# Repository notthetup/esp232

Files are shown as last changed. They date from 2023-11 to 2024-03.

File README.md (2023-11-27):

# esp232
ESP32 + RS232 = 💰

This project is a simple PCB that allows you to connect an ESP32 to a RS232 port. The initial version is based on a Seeduino ESP32 Xiao board for simplicity.

## Features

- RS232 port with RTS/CTS flow control
- USB port for power and programming
- Seperate optional 5V power input
- Commonly available IDC connectors for connecting to RS232.

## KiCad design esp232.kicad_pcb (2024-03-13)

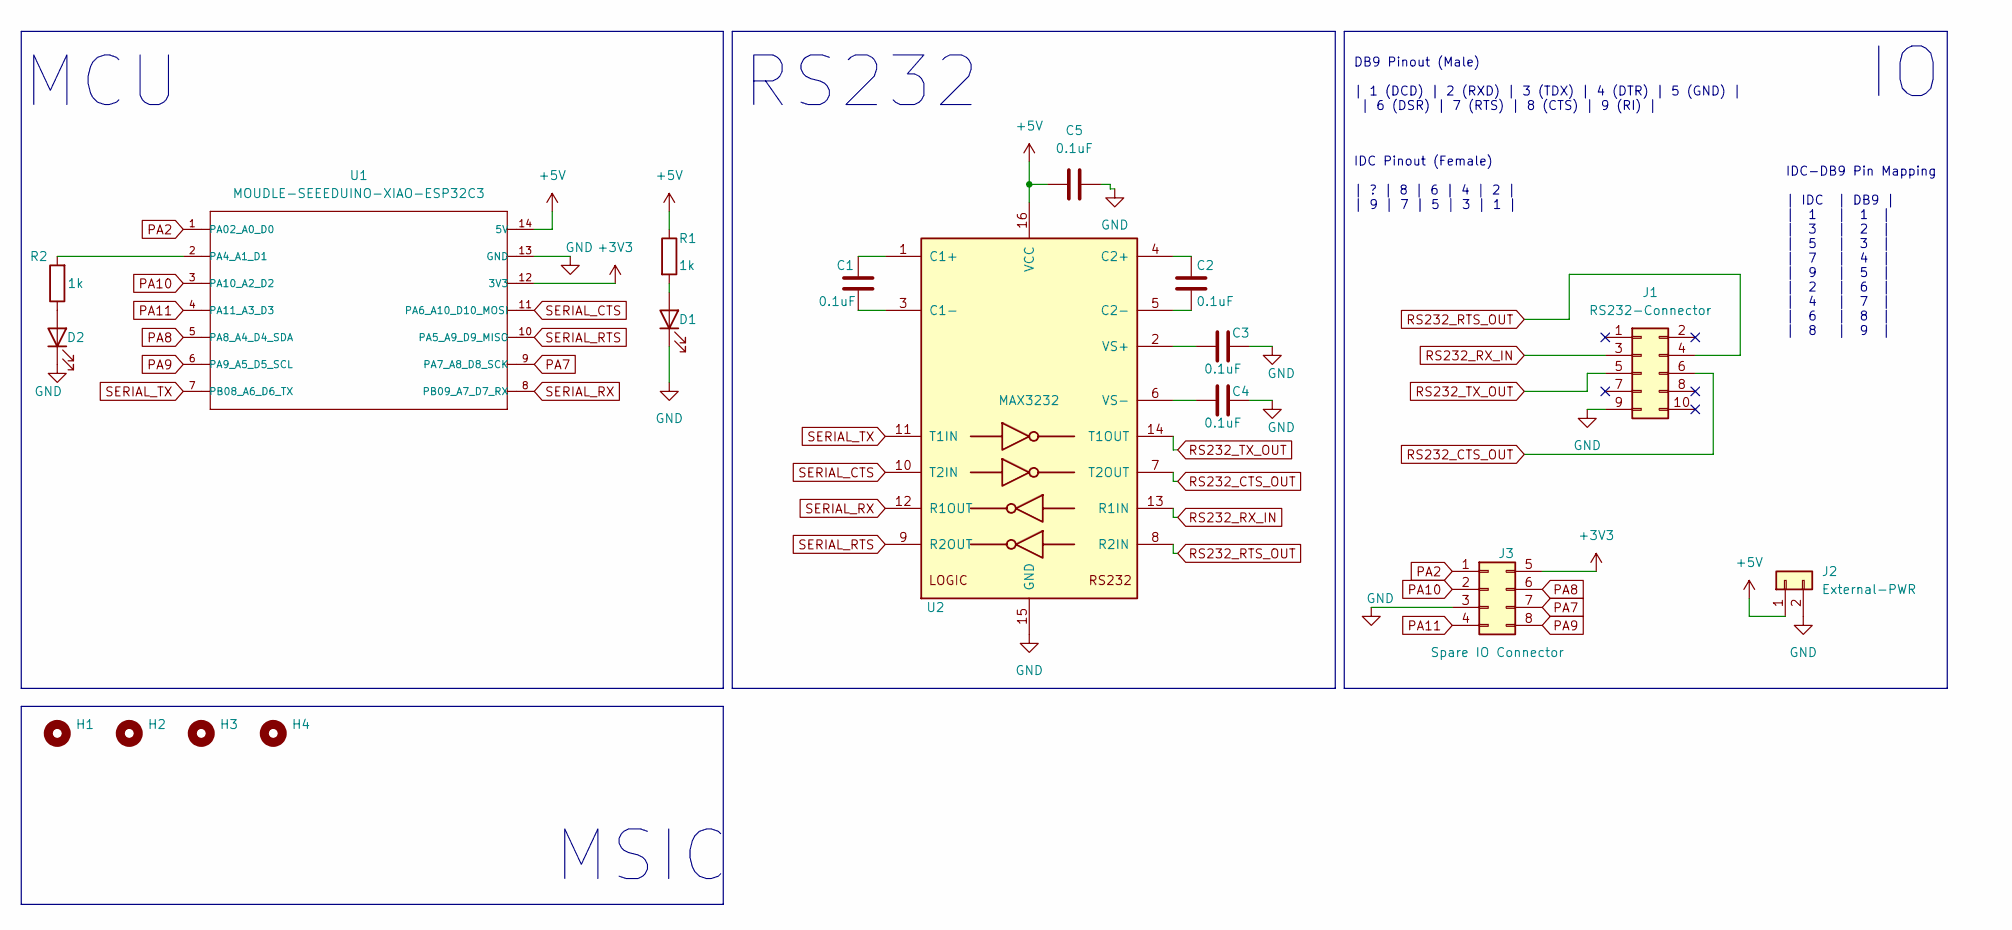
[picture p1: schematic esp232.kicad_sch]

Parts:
C1, C2, C3, C4, C5: 0.1uF; C_0805_2012Metric_Pad1.18x1.45mm_HandSolder
D1, D2: LED; LED_0805_2012Metric_Pad1.15x1.40mm_HandSolder
H1, H2, H3, H4: MountingHole; MountingHole_2.5mm
J1: RS232-Connector; IDC-Header_2x05_P2.54mm_Vertical
J2: External-PWR; PinHeader_1x02_P1.27mm_Vertical
J3: Spare IO Connector; PinHeader_2x04_P1.27mm_Vertical_SMD
R1, R2: 1k; R_0805_2012Metric_Pad1.20x1.40mm_HandSolder
U1: MOUDLE-SEEEDUINO-XIAO-ESP32C3; MOUDLE14P-SMD-2.54-21X17.8MM
U2: MAX3232; SOIC-16_3.9x9.9mm_P1.27mm

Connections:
+3V3: J3.5, U1.12 (3V3)
+5V: C5.1, J2.1, R1.1, U1.14 (5V), U2.16 (VCC)
GND: C3.2, C4.2, C5.2, D1.1 (K), D2.1 (K), J1.9, J2.2, J3.3, U1.13 (GND), U2.15 (GND)
unnamed: D1.2 (A), R1.2
unnamed: D2.2 (A), R2.1
unnamed: R2.2, U1.2 (PA4_A1_D1)
unnamed: C1.1, U2.1 (C1+)
unnamed: C1.2, U2.3 (C1-)
unnamed: C2.1, U2.4 (C2+)
unnamed: C2.2, U2.5 (C2-)
unnamed: C3.1, U2.2 (VS+)
unnamed: C4.1, U2.6 (VS-)
PA2: J3.1, U1.1 (PA02_A0_D0)
PA7: J3.7, U1.9 (PA7_A8_D8_SCK)
PA8: J3.6, U1.5 (PA8_A4_D4_SDA)
PA9: J3.8, U1.6 (PA9_A5_D5_SCL)
PA10: J3.2, U1.3 (PA10_A2_D2)
PA11: J3.4, U1.4 (PA11_A3_D3)
RS232_CTS_OUT: J1.6, U2.7 (T2OUT)
RS232_RTS_OUT: J1.4, U2.8 (R2IN)
RS232_RX_IN: J1.3, U2.13 (R1IN)
RS232_TX_OUT: J1.5, U2.14 (T1OUT)
SERIAL_CTS: U1.11 (PA6_A10_D10_MOSI), U2.10 (T2IN)
SERIAL_RTS: U1.10 (PA5_A9_D9_MISO), U2.9 (R2OUT)
SERIAL_RX: U1.8 (PB09_A7_D7_RX), U2.12 (R1OUT)
SERIAL_TX: U1.7 (PB08_A6_D6_TX), U2.11 (T1IN)

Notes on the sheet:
DB9 Pinout (Male) | 1 (DCD) | 2 (RXD) | 3 (TDX) | 4 (DTR) | 5 (GND) | | 6 (DSR) | 7 (RTS) | 8 (CTS) | 9 (RI) |
MCU
IDC Pinout (Female) | ? | 8 | 6 | 4 | 2 | | 9 | 7 | 5 | 3 | 1 |
IDC-DB9 Pin Mapping | IDC | DB9 | | 1 | 1 | | 3 | 2 | | 5 | 3 | | 7 | 4 | | 9 | 5 | | 2 | 6 | | 4 | 7 | | 6 | 8 | | 8 | 9 |
RS232
MSIC

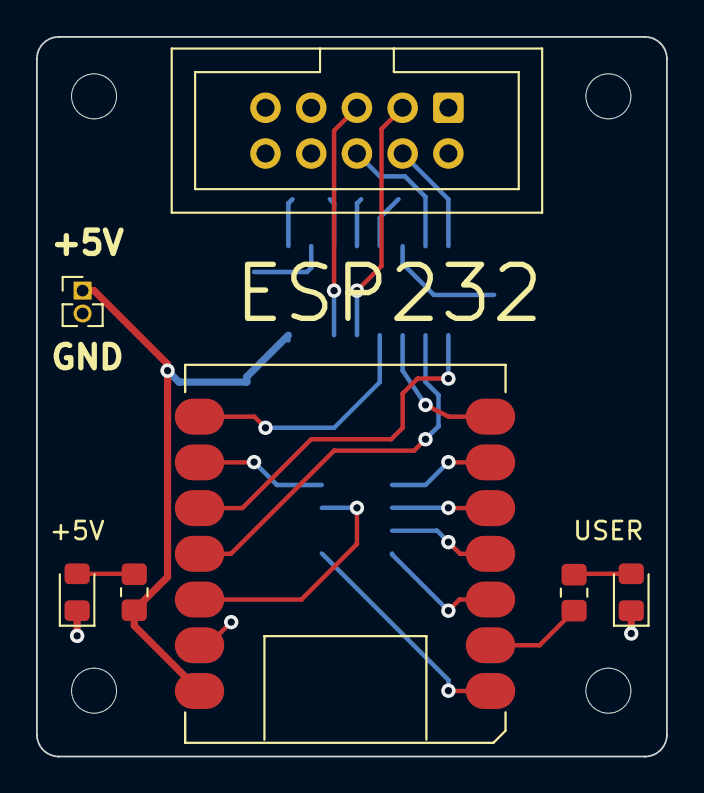
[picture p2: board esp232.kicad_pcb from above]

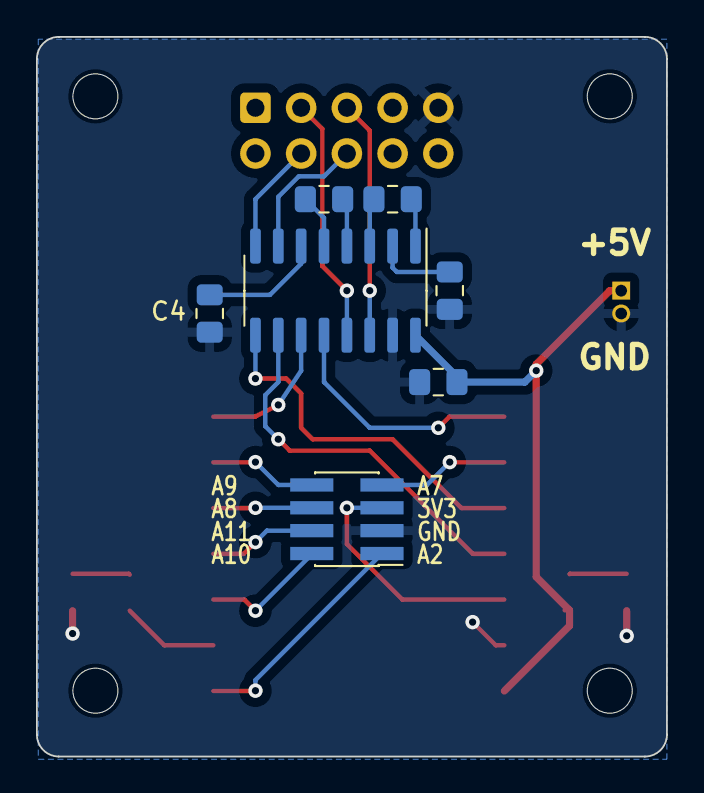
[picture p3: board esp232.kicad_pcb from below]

Board: 2 copper layers, 35.0 x 40.0 mm, 18 parts (7 on the bottom side), 26 nets.

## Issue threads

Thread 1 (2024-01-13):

Review comments

notthetup, 2024-01-13:
1. The symbol for Speed XIAO has all bidirectional pins, so the ERC is failing with power flag conflicts. (Not so important)
2. Define another thicker net class for power so that 5V, 3V3 and GND have thicker traces.
3. Run the DRC in layout also. Lots of silkscreen clipping errors.

notthetup, 2024-01-13:
Fixed in 25c5f8a096bab09de35d5ce5f288d7be972157d5

Closed 2024-01-13.

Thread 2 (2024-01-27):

Layout improvements

notthetup, 2024-01-27:
- [ ] Pin1 Marking for the 3232 transceiver IC
- [ ] Led polarity
- [ ] Designators for Capacitors and Resistors
- [ ] 5V breakout => 2.54mm pin pitch
- [ ] more curved corners

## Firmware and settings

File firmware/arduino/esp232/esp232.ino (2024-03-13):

#include <esp_wifi.h>
#include <WiFi.h>
#include <ArduinoOTA.h>
#include <ESPmDNS.h>

#define BAUD 9600
#define WDT_TIMEOUT 10
#define SERIAL_TCP_PORT 8880

const char* ssid = "<name of your access point>";
const char* password =  "<password of your access point>";
const char* mdns_name = "ESP232";

HardwareSerial HWSerial(0);   //Create a new HardwareSerial class.

WiFiServer wifiServer(SERIAL_TCP_PORT);

int last = millis();
bool ledStatus = false;

void setup() {
  HWSerial.begin(BAUD, SERIAL_8N1, RX, TX);
  HWSerial.setRxBufferSize(8192);
  Serial.begin(115200);

  delay(1000);

  WiFi.setHostname(mdns_name);
  WiFi.begin(ssid, password);

  while (WiFi.status() != WL_CONNECTED) {
    delay(1000);
    Serial.println("Connecting to WiFi..");
  }

  Serial.println("Connected to the WiFi network");
  Serial.println(WiFi.localIP());

  wifiServer.begin();

  if (!MDNS.begin(mdns_name)) {
    Serial.println("Error starting mDNS");
    return;
  }

  pinMode(D1, OUTPUT);
}

void toogleLED(){
  ledStatus = !ledStatus;
  digitalWrite(D1, ledStatus);
}

void loop() {
  // resetting WDT every 1s
  if (millis() - last >= 1000) {
    last = millis();
  }

  WiFiClient client = wifiServer.available();
  if (client) {
    Serial.println("Client connected");
    while (client.connected()) {
      if (HWSerial.available()) {
        toogleLED();
        client.write(HWSerial.read());
      }
      if (client.available()) {
        HWSerial.write(client.read());
      }
    }
    Serial.println("Client disconnected");
  }else {
    // Empty the Serial buffer
    int bytes = HWSerial.available();
    for (int i = 0; i < bytes; i++) {
      HWSerial.read();
    }
  }
}

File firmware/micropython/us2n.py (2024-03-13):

# us2n.py

import json
import time
import select
import socket
import machine
import network

print_ = print
VERBOSE = 1
def print(*args, **kwargs):
    if VERBOSE:
        print_(*args, **kwargs)


def read_config(filename='us2n.json', obj=None, default=None):
    with open(filename, 'r') as f:
        config = json.load(f)
        if obj is None:
            return config
        return config.get(obj, default)


def parse_bind_address(addr, default=None):
    if addr is None:
        return default
    args = addr
    if not isinstance(args, (list, tuple)):
        args = addr.rsplit(':', 1)
    host = '' if len(args) == 1 or args[0] == '0' else args[0]
    port = int(args[1])
    return host, port

class RINGBUFFER:
    def __init__(self, size):
        self.data = bytearray(size)
        self.size = size
        self.index_put = 0
        self.index_get = 0
        self.index_rewind = 0
        self.wrapped = False

    def put(self, data):
        cur_idx = 0
        while cur_idx < len(data):
            min_idx = min(self.index_put+len(data)-cur_idx, self.size)
            self.data[self.index_put:min_idx] = data[cur_idx:min_idx-self.index_put+cur_idx]
            cur_idx += min_idx-self.index_put
            if self.index_get > self.index_put:
                self.index_get = max(min_idx+1, self.index_get)
                if self.index_get >= self.size:
                    self.index_get -= self.size
            self.index_put = min_idx
            if self.index_put == self.size:
                self.index_put = 0
                self.wrapped = True
                if self.index_get == 0:
                    self.index_get = 1

    def putc(self, value):
        next_index = (self.index_put + 1) % self.size
        self.data[self.index_put] = value
        self.index_put = next_index
        # check for overflow
        if self.index_get == self.index_put:
            self.index_get = (self.index_get + 1) % self.size
        return value

    def get(self, numbytes):
        data = bytearray()
        while len(data) < numbytes:
            start = self.index_get
            min_idx = min(self.index_get+numbytes-len(data), self.size)
            if self.index_put >= self.index_get:
                min_idx = min(min_idx, self.index_put)
            data.extend(self.data[start:min_idx])
            self.index_get = min_idx
            if self.index_get == self.size:
                self.index_get = 0
            if self.index_get == self.index_put:
                break
        return data

    def getc(self):
        if not self.has_data():
            return None  ## buffer empty
        else:
            value = self.data[self.index_get]
            self.index_get = (self.index_get + 1) % self.size
            return value

    def has_data(self):
        return self.index_get != self.index_put

    def rewind(self):
        if self.wrapped:
            self.index_get = (self.index_put+1) % self.size
        else:
            self.index_get = 0

def UART(config):
    config = dict(config)
    uart_type = config.pop('type') if 'type' in config.keys() else 'hw'
    port = config.pop('port')
    if uart_type == 'SoftUART':
        print('Using SoftUART...')
        uart = machine.SoftUART(machine.Pin(config.pop('tx')),machine.Pin(config.pop('rx')),timeout=config.pop('timeout'),timeout_char=config.pop('timeout_char'),baudrate=config.pop('baudrate'))
    else:
        print('Using HW UART...')
        uart = machine.UART(port)
        uart.init(**config)
    return uart


class Bridge:

    def __init__(self, config):
        super().__init__()
        self.config = config
        self.uart = None
        self.uart_port = config['uart']['port']
        self.tcp = None
        self.address = parse_bind_address(config['tcp']['bind'])
        self.bind_port = self.address[1]
        self.client = None
        self.client_address = None
        self.ring_buffer = RINGBUFFER(16 * 1024)
        self.cur_line = bytearray()
        self.state = 'listening'
        self.uart = UART(self.config['uart'])
        print('UART opened ', self.uart)
        print(self.config)

    def bind(self):
        tcp = socket.socket()
        tcp.setsockopt(socket.SOL_SOCKET, socket.SO_REUSEADDR, 1)
        tcp.bind(self.address)
        tcp.listen(5)
        print('Bridge listening at TCP({0}) for UART({1})'
              .format(self.bind_port, self.uart_port))
        self.tcp = tcp
        if 'ssl' in self.config:
            import ntptime
            ntptime.host = "pool.ntp.org"
            while True:
                try:
                    ntptime.settime()
                except OSError as e:
                    print(f"NTP synchronization failed, {e}")
                    time.sleep(15)
                    continue
                print(f"NTP synchronization succeeded, {time.time()}")
                print(time.gmtime())
                break

        return tcp

    def fill(self, fds):
        if self.uart is not None:
            fds.append(self.uart)
        if self.tcp is not None:
            fds.append(self.tcp)
        if self.client is not None:
            fds.append(self.client)
        return fds

    def recv(self, sock, n):
        if hasattr(sock, 'recv'):
            return sock.recv(n)
        else:
            # SSL-wrapped sockets don't have recv(), use read() instead
            # TODO: Read more than 1 byte? Probably needs non-blocking sockets
            return sock.read(1)

    def sendall(self, sock, bytes):
        if hasattr(sock, 'sendall'):
            return sock.sendall(bytes)
        else:
            # SSL-wrapped sockets don't have sendall(), use write() instead
            return sock.write(bytes)
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

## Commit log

2023-12-20 updated schematic and layout
    [esp232.kicad_pcb, esp232.kicad_sch]
2023-12-21 small layout improvements
    [esp232.kicad_pcb, esp232.kicad_sch]
2024-01-13 fixed review comments
    [esp232.kicad_pcb, esp232.kicad_sch]
2024-03-13 updating firmware
    [esp232.kicad_pcb]
